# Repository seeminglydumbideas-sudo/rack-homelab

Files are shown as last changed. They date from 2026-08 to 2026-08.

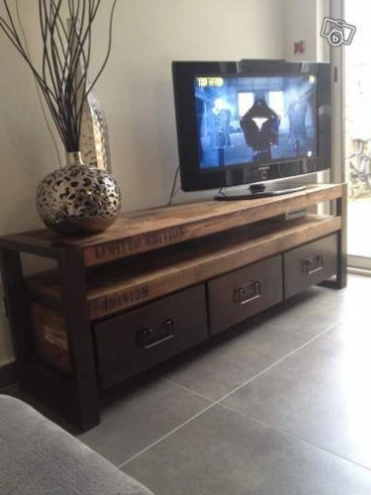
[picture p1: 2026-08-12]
rack_10inches/references/Selection_010.png

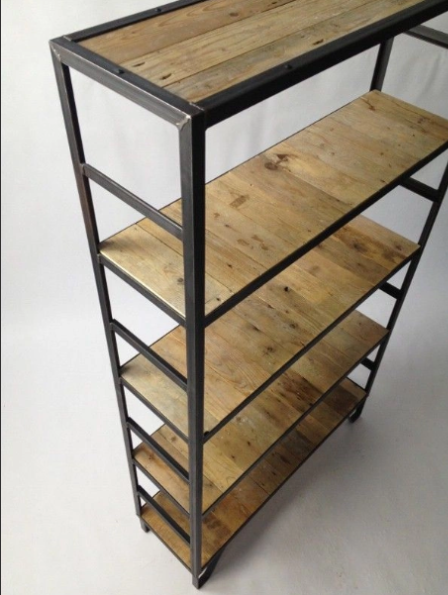
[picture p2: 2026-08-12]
rack_10inches/references/Selection_008.png

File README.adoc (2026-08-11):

= Homelab Mini Rack Project

== Context
This is a personal project aimed at learning and practicing multiple maker disciplines: woodworking, 3D printing, and soldering. A huge thanks to the **Y-FabLab** community for the help and resources that make this project possible!

== Goal of the Project
The objective is to build a small rack for a home lab. Instead of a generic server rack, this project aims for a highly custom vintage/industrial aesthetic, combining raw steel square tubes with dark wooden
panels. 

It is designed to cleanly house and manage small devices:
* Raspberry Pis
* GMKTec mini PCs
* Network switches
* A dedicated technical zone for power management (power strips, 8x USB charger
  hubs, and specific power bricks for mini PCs).

== The First Attempt: `stackable-3d-prints`
The initial version of this project was entirely based on 3D printed stackable modules. However, I decided to abandon it and pivot to a new architecture due
to several critical limitations:
* **Thermal Management**: Stacked closed plastic boxes provided poor airflow
  for the SBCs.
* **Cable Management**: Routing network and power cables through the stack
  became an absolute nightmare.
* **Accessibility**: Accessing or swapping a device in the middle of the stack
  meant dismantling everything above it.

== The Current Version: `rack_10inches`
To solve the previous issues, the project evolved into a custom hybrid
metal/wood rack.

=== Design & Style
The design leverages an industrial and vintage style. The skeleton is made of
15x15mm steel square profiles, dressed with wooden panels (sides, top, and
base). This creates an open-frame internal structure that guarantees excellent
airflow and massive space in the back for cables, while looking like a stylish
piece of furniture.

=== Dimensions & Standard
Instead of the massive 19-inch standard, this rack is built around the
**10-inch rack standard**, which is the perfect footprint for Raspberry Pis and
mini PCs. The internal height is 22U (approximately 1 meter tall). 

The inner faces of the steel profiles are drilled with standard EIA-310 rack
holes.

=== The Toolless Mounting Clip
One of the major innovations in this design is how the front plates attach to
the steel frame. Instead of tapping holes directly into the steel to screw the
panels, I designed a custom 3D-printable mounting bracket.
* It features a snap-fit conical peg at the bottom.
* It features a half-cylinder peg with a hook at the top.
* **How it works:** You tilt the printed piece to insert the top hook into the
  chassis hole, then pivot it down. The bottom peg snaps into the lower hole,
  locking the piece securely to the frame without a single screw on the chassis
  side. The front plates are then screwed into an M5 heat-set threaded insert
  melted into the bracket.

image::rack_10inches/rack_assembly.scad — OpenSCAD_001.png[Rack Assembly Overview]

=== Modeling with OpenSCAD and Antigravity
The entire project is parametrically modeled using **OpenSCAD**, allowing for
precise, code-driven adjustments of all dimensions and components. I 
collaborated with the Antigravity AI agent to assist in iterating on the
design, precisely calculating the EIA-310 hole spacing, and engineering the
complex geometric `hull()` shapes for the toolless mounting clips.

image::rack_10inches/rack_assembly.scad — OpenSCAD_002.png[OpenSCAD Detail View]

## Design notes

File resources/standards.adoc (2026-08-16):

= 10-Inch Rack Standards
:toc:
:icons: font

== Overview

Unlike 19-inch racks (which strictly follow the EIA-310 / IEC 60297 standard), the "10-inch" (or mini-rack) format does not have an official worldwide standard. Manufacturers generally adapt the 19-inch specifications to a smaller form factor, leading to slight variations between brands.

However, the industry has converged on a general "unwritten consensus" for 10-inch panels and racks, documented below.

== Vertical Dimensions (Height)

The vertical spacing exactly mirrors the 19-inch EIA-310 standard.

* **1 Rack Unit (1U):** 1.75 inches (44.45 mm)
* **Hole Spacing within 1U:** The standard 3-hole pattern uses distances of 5/8" (15.875 mm), 5/8" (15.875 mm), and 1/2" (12.7 mm) from center to center.

== Horizontal Dimensions (Width)

Because there is no official governing body, horizontal dimensions vary the most between manufacturers.

* **Total Panel Width:** Exactly 10 inches (254 mm)
* **Usable Inner Opening (Between Rails):** Usually about 8.75 inches (222 mm)
* **Center-to-Center Hole Distance:** Typically ranges between 236 mm and 241 mm (9.3" to 9.5")

== Depth Dimensions

Unlike 19-inch racks (which have common standard depths like 600mm, 800mm, or 1000mm), **there is no standard depth for 10-inch racks.** Depth varies entirely by manufacturer and the intended use-case (e.g., a shallow cabinet for patch panels vs. a deeper cabinet for a mini NAS or switch).

* **Current CAD Value:** In this project, the `rack_depth` is set to 300 mm. Factoring in the front and rear metal frame profiles (15 mm each), the **distance between the front and rear mounting rails is exactly 270 mm**.
* **Recommendation:** When designing equipment that relies on 4-post mounting (like a heavy server tray), always measure the actual physical depth of your rails or design your rear mounts to be adjustable (using sliding rails).

=== Recommended CAD Dimensions

To ensure maximum compatibility when designing custom 10-inch rack equipment (such as 3D-printed or CNC-milled front plates), we use the following measurements in this project:

* **Panel Width:** `254 mm`
* **Horizontal Hole Spacing:** `236 mm` (This aligns perfectly with standard 20mm commercial rails mounted to our frame)

[TIP]
====
It is highly recommended to use slotted or slightly oversized holes (e.g., oval holes) for the horizontal mounting points on any custom panels. This allows for a few millimeters of wiggle room to accommodate different commercial rail manufacturers.
====

== Commercial Rack Rails (Example)

Based on commonly available "DIY Server Rack Rails" (e.g., 8U rails from AliExpress), the physical dimensions of standard commercial L-profile rails are typically:

* **Length (8U):** 35.5 cm (13.98 in)
* **Front Face (Square Holes):** 2.0 cm (0.787 in) width
* **Side Face (Mounting Face):** 2.7 cm (1.06 in) depth
* **Side Mounting Holes:** Typically 8 round holes per 8U strip, each with a diameter of 0.25 inches (~6.35 mm).

These dimensions are highly typical for cheap, mass-produced server rack rails. When designing a frame, you must account for the 2.0 cm width of the front face to ensure your 10-inch equipment still aligns properly (as addressed in our CAD model by setting the side margin to 1mm).

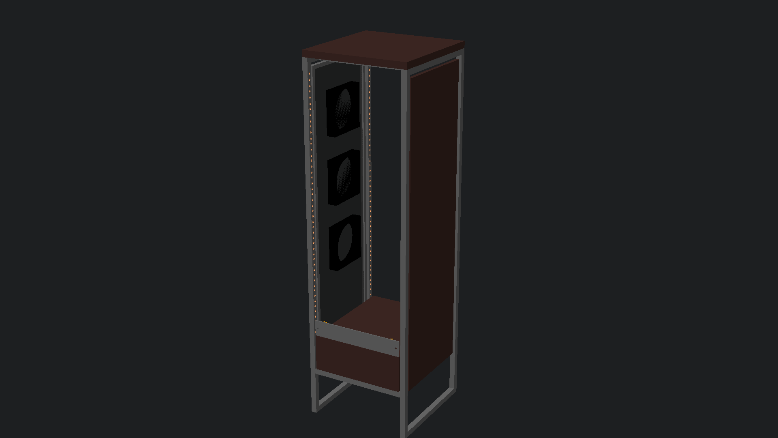
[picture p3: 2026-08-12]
screenshots/rack_rendered_20260812_151010.png

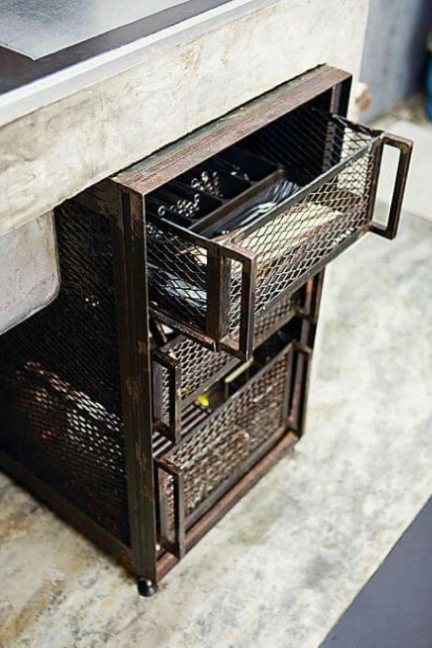
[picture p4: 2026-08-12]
rack_10inches/references/Selection_009.png

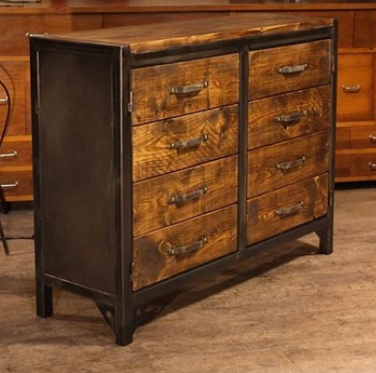
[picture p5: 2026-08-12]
rack_10inches/references/Selection_004.png

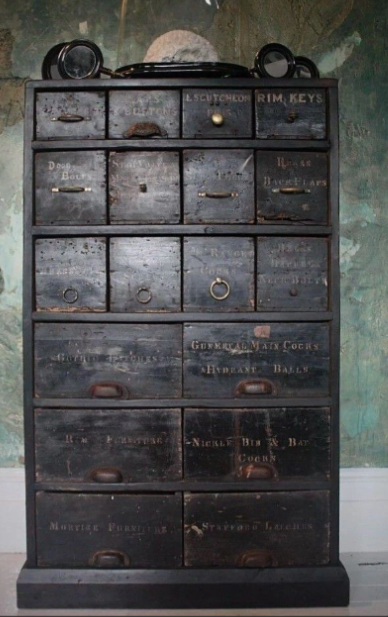
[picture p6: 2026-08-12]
rack_10inches/references/Selection_006.png

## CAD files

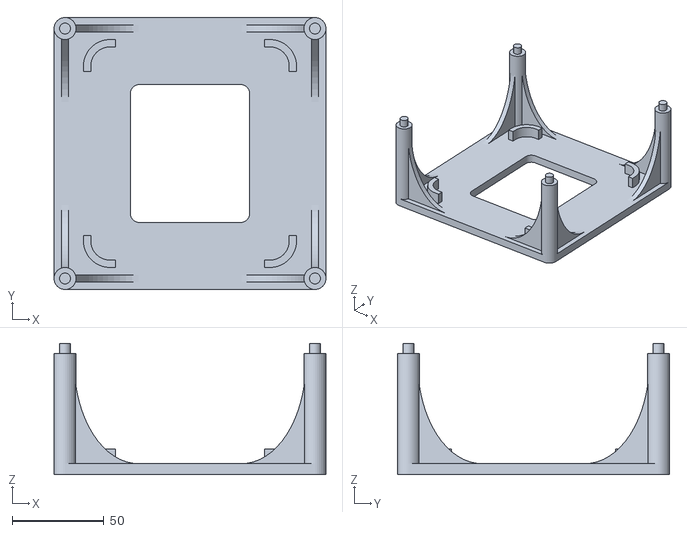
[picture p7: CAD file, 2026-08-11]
stackable-3d-prints/print0.stl
148.0 x 148.0 x 71.5

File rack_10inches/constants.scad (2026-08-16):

// Constantes pour le meuble Rack 10 pouces
// Unité de base : mm
$fn=100; // [100:high,6:low]

// Unité de rack (U) standard
U = 44.45;

// Hauteur totale du châssis en métal (longueur des profilés verticaux)
// Vous pouvez ajuster cette valeur pour vos découpes (ex: 980, 1000, 1200...)
rack_height = 980;

// Dimensions internes du rack
// --- Dimensions des panneaux (10 pouces) ---
panel_width = 254; // Largeur standard d'un panneau 10 pouces
panel_margin = 1;  // Marge ajustée pour centrer les rails commerciaux (les rails font 20mm de face)
frame_gap = 10; // Espace entre le rail commercial et le cadre métallique (de chaque côté)
mounting_plate_thickness = 4; // Epaisseur de la plaque de montage pour les rails (fer plat)
mounting_plate_depth = 25; // Largeur du fer plat utilisé pour la plaque de montage

// Largeur utile interne (entre les rails)
rack_internal_width = 236; 

// Dimensions des matériaux structurels de base
metal_profile_size = 16; // Profilé carré acier 16x16mm

// Profondeur du meuble
rack_internal_depth = 300; // Espace libre entre le rail avant et le rail arrière
rail_depth_margin = 10; // Recul du rail par rapport au bord du cadre (avant et arrière)
rack_depth = (metal_profile_size * 2) + (rail_depth_margin * 2) + rack_internal_depth; // 350mm de profondeur totale

tech_zone_depth = 100; // 10 cm pour les alims et câbles au fond
device_zone_depth = rack_depth - tech_zone_depth; // 20 cm pour les appareils

// Dimensions des matériaux additionnels
commercial_rail_thickness = 2; // Epaisseur de la tôle du rail commercial
commercial_rail_front = 20; // Largeur de la face avant du rail (avec les trous carrés)
commercial_rail_side = 27; // Profondeur du rail (face vissée sur le profilé)
wood_thickness_top = 18; // Épaisseur de la planche supérieure (toit)
wood_thickness_side = 10; // Épaisseur des panneaux latéraux (idem cadre ventilation)
wood_thickness_bottom = 100; // Épaisseur de la planche inférieure (base massive)
wood_overhang = 0; // Aucun débordement, la planche est à fleur du cadre

ground_clearance = 120; // Espace libre sous le meuble (pour robot aspirateur)

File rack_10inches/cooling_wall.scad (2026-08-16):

include <constants.scad>

module square_profile_mesh(w, d, h) {
    color("DimGray")
    cube([w, d, h]);
}

// ==========================================
// Paroi latérale gauche en grillage pour ventilateurs
// ==========================================
module cooling_mesh_wall() {
    // Épaisseur du sous-cadre du grillage (profilés acier plus fins, ex: 10x10mm)
    frame = 10;
    
    // Positionnement dans la "fenêtre" du cadre gauche (qui fait metal_profile_size d'épaisseur)
    x_offset = (metal_profile_size - frame) / 2; // Centré dans l'épaisseur du profilé
    
    // Espace libre tout autour du sous-cadre
    gap = 10;
    
    // Profondeur disponible (entre le montant avant et arrière, moins les espaces)
    w = (rack_depth - 2 * metal_profile_size) - 2 * gap; 
    
    // Hauteur disponible (démarre de ground_clearance jusqu'à la barre supérieure, moins les espaces)
    h_total = rack_height;
    h = (h_total - metal_profile_size - ground_clearance) - 2 * gap;
    
    translate([x_offset, metal_profile_size + gap, ground_clearance + gap]) {
        // --- Cadre du grillage ---
        // Montants verticaux
        square_profile_mesh(frame, frame, h);
        translate([0, w - frame, 0]) square_profile_mesh(frame, frame, h);
        
        // Traverses horizontales
        translate([0, frame, 0]) square_profile_mesh(frame, w - 2*frame, frame);
        translate([0, frame, h - frame]) square_profile_mesh(frame, w - 2*frame, frame);
        
        // --- Le grillage ---
        // Représenté par un plan semi-transparent pour ne pas alourdir la 3D
        color([0.2, 0.2, 0.2, 0.5])
        translate([frame/2 - 1, frame, frame])
            cube([2, w - 2*frame, h - 2*frame]);
            
        // --- Ventilateurs (simulation 120mm) ---
        fan_size = 120;
        fan_thick = 25;
        num_fans = 4; // On place 4 ventilateurs espacés
        spacing_z = (h - 2*frame - num_fans*fan_size) / (num_fans + 1);
        
        // On retire le ventilateur le plus bas en commençant la boucle à 1 au lieu de 0
        for(i = [1 : num_fans - 1]) {
            fan_z = frame + spacing_z + i*(fan_size + spacing_z);
            // On centre les ventilateurs en Y (profondeur)
            fan_y = (w - fan_size) / 2;
            
            // Fixés côté intérieur du grillage (ils débordent dans le rack)
            color("Black")
            translate([frame/2 + 1, fan_y, fan_z])
                difference() {
                    // Corps du ventilateur
                    cube([fan_thick, fan_size, fan_size]);
                    // Trou circulaire du rotor
                    translate([-1, fan_size/2, fan_size/2])
                        rotate([0, 90, 0])
                        cylinder(r=fan_size/2 - 3, h=fan_thick + 2, $fn=32);
                }
        }
    }
}

// Affichage de test si on ouvre juste ce fichier
// cooling_mesh_wall();

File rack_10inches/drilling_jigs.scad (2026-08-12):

include <constants.scad>

// Tolérance pour glisser sur le tube acier
play = 0.4; // 0.4mm de marge totale (0.2 par côté) pour glisser facilement sans forcer
inner_w = metal_profile_size + play;
inner_d = metal_profile_size + play;

wall_thick = 4; // Épaisseur de la face de perçage (suffisante pour bien guider le foret)
side_thick = 3; // Épaisseur des pattes latérales du U

drill_radius = 3.0; // Pour un foret métal de 6mm

// Forme de base (U-channel) qui vient épouser le profilé carré
module u_channel_profile() {
    difference() {
        // Bloc extérieur
        square([inner_w + 2*side_thick, inner_d + wall_thick]);
        // Creux intérieur pour le profilé acier
        translate([side_thick, wall_thick])
            square([inner_w, inner_d + 1]); 
    }
}

// ==========================================
// Gabarit 1 : DÉMARREUR
// À poser en butée sur la traverse horizontale en acier.
// Il donne automatiquement la hauteur parfaite pour les 2 premiers trous,
// en prenant en compte l'épaisseur de la planche en bois.
// ==========================================
module starter_jig() {
    // Hauteur du premier trou par rapport à la traverse acier
    h1 = wood_thickness_bottom + 6.35;
    h2 = h1 + 15.875;
    
    height = h2 + 10; // On ajoute 10mm de marge au-dessus
    
    color("Cyan")
    difference() {
        linear_extrude(height) u_channel_profile();
            
        // Trou 1
        translate([side_thick + inner_w/2, 0, h1])
            rotate([-90, 0, 0])
            cylinder(r=drill_radius, h=wall_thick*3, center=true, $fn=32);
            
        // Trou 2
        translate([side_thick + inner_w/2, 0, h2])
            rotate([-90, 0, 0])
            cylinder(r=drill_radius, h=wall_thick*3, center=true, $fn=32);
            
        // Gravure "1"
        translate([side_thick + inner_w/2, 1, h1/2])
            rotate([90, 0, 0])
            linear_extrude(2)
            text("1", size=6, halign="center", valign="center");
    }
}

// ==========================================
// Gabarit 2 : EXTENSION
// À brancher dans les 2 trous précédents via ses tétons.
// Permet de percer les 3 trous suivants avec l'espacement parfait EIA-310.
// (Il suffit de le décaler de 2 trous en 2 trous pour faire toute la hauteur).
// ==========================================
module extension_jig() {
    z_offset = 10; // Marge en bas pour solidifier les tétons
    
    // Distances standard EIA-310 : 15.875, 15.875, 12.7
    // Tétons insérés dans les trous 0 et 1 (espacés de 15.875)
    t0 = 0;
    t1 = 15.875;
    
    // Nouveaux trous à percer
    t2 = t1 + 15.875; // 31.75
    t3 = t2 + 12.7;   // 44.45
    t4 = t3 + 15.875; // 60.325
    
    height = t4 + z_offset + 10; 
    
    color("LimeGreen")
    union() {
        difference() {
            // Corps
            linear_extrude(height) u_channel_profile();
                
            // Trous de perçage
            for (z = [t2, t3, t4]) {
                translate([side_thick + inner_w/2, 0, z + z_offset])
                    rotate([-90, 0, 0])
                    cylinder(r=drill_radius, h=wall_thick*3, center=true, $fn=32);
            }
            
            // Gravure "2"
            translate([side_thick + inner_w/2, 1, z_offset + t2/2])
                rotate([90, 0, 0])
                linear_extrude(2)
                text("2", size=6, halign="center", valign="center");
        }
        
        // Tétons de centrage (rentrent dans les trous de 6mm du châssis)
        // Coniques pour une insertion facile et sans jeu (r base = 2.8, r pointe = 2.0)
        for (z = [t0, t1]) {
            translate([side_thick + inner_w/2, wall_thick, z + z_offset])
                rotate([-90, 0, 0])
                cylinder(r1=2.8, r2=2.0, h=4, $fn=32);
        }
    }
}

// Affichage par défaut pour générer les STL
translate([-20, 0, 0]) starter_jig();
translate([20, 0, 0]) extension_jig();

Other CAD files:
rack_10inches/front_plate.scad
rack_10inches/front_plate_mount.scad
rack_10inches/rack_assembly.scad
rack_10inches/technical_zone.scad
stackable-3d-prints/gmktec.scad
stackable-3d-prints/main.scad
stackable-3d-prints/printable.scad
stackable-3d-prints/raspi-ssd.scad
stackable-3d-prints/raspi_3b.scad
stackable-3d-prints/raspi_4b.scad

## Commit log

2026-08-12 add faces, quotes, etc.
    [constants.scad, cooling_wall.scad, drilling_jigs.scad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]
2026-08-13 2nd U
    [front_plate_mount.scad, rack_assembly.scad]
2026-08-15 pre using commercial rack rails
    [front_plate_mount.scad, rack_assembly.scad]
2026-08-16 feat(rack): update to 16x16mm profiles, dynamic depth, miter joints, and 25x4mm mounting plates
    - Switch to 16x16mm steel profiles
    - Implement dynamic internal depth (300mm + 20mm margin)
    - Convert main side frames to use 45-degree miter cuts
    - Add EIA-310 compliant slotted hole spacing for faceplates
    - Update rail mounting plates to 25x4mm steel flat bar
    - Add 3mm steel rod diagonal bottom braces for mounting plates
    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
    [constants.scad, cooling_wall.scad, front_plate.scad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]
